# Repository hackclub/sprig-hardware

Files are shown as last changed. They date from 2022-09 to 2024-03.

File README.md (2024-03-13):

# This repository has been deprecated. This project is now maintained at https://github.com/hackclub/sprig/tree/main/hardware
## If you're looking for instructions on assembling your sprig, check out our [assembly guide!](https://github.com/hackclub/sprig/blob/main/docs/ASSEMBLY.md)

---

## The Sprig Console

You can find KiCAD 6 files for the PCB of Sprig, a BOM, and CAD models for the acrylic back covers here.

- `hardware/` contains the KiCAD files and Bill of Materials for the PCB
- `back_covers/` contains the CAD models for the acrylic back covers

The main [Sprig Repo is available here](https://www.github.com/hackclub/sprig).

Assembled Green Sprig, Front View

Assembled Green Sprig, Rear View

# Description

The Sprig console is a custom-designed, limited edition game console powered by the Raspberry Pi Pico. It has a 1.8" 160x128 LCD display, as well as eight tactile buttons for input. It uses two AAA batteries for power, and has a MAX98357A audio amplifier with an 8 ohm, 300mW Speaker.

The Sprig console is a custom-designed, limited edition game console built to run games written with the Sprig game editor.

It's powered by a Raspberry Pi RP2040, which is clocked at 125MHz, with 264kB SRAM and 2MB external QSPI flash. Four unused GPIO pins are exposed to the rear of the console.

The Sprig is powered by two AAA batteries. There is also a high efficiency schottky diode to prevent power flow to the batteries when connected to USB power.

In addition, there is a MAX98357A class D audio amplifier from Maxim Integrated, connected to a CUI Devices CVS-1508 8 ohm, 300mW speaker.

There are two LEDs for status, a power switch for batteries, as well as eight tactile buttons to control input.

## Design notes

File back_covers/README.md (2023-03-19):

# Back Covers for Sprig



`sprig_cover.f3d` is the Fusion 360 file for the back cover. The back covers can be secured with M2 x 10mm screws and hex nuts.

If you choose to fabricate the back covers using a laser cutter, you'll need 2 pieces which are `sprig_cover--dpad.dxf` and `sprig_cover--solid.dxf`. One piece has a d-pad cutout for the buttons. It's designed to be cut out of 1/8" or 3mm acrylic.

To fabricate the back covers using a 3D printer, you'll need to print 2 of the `sprig_cover--dpad.stl` and 2 of the `sprig_cover--solid.stl`.

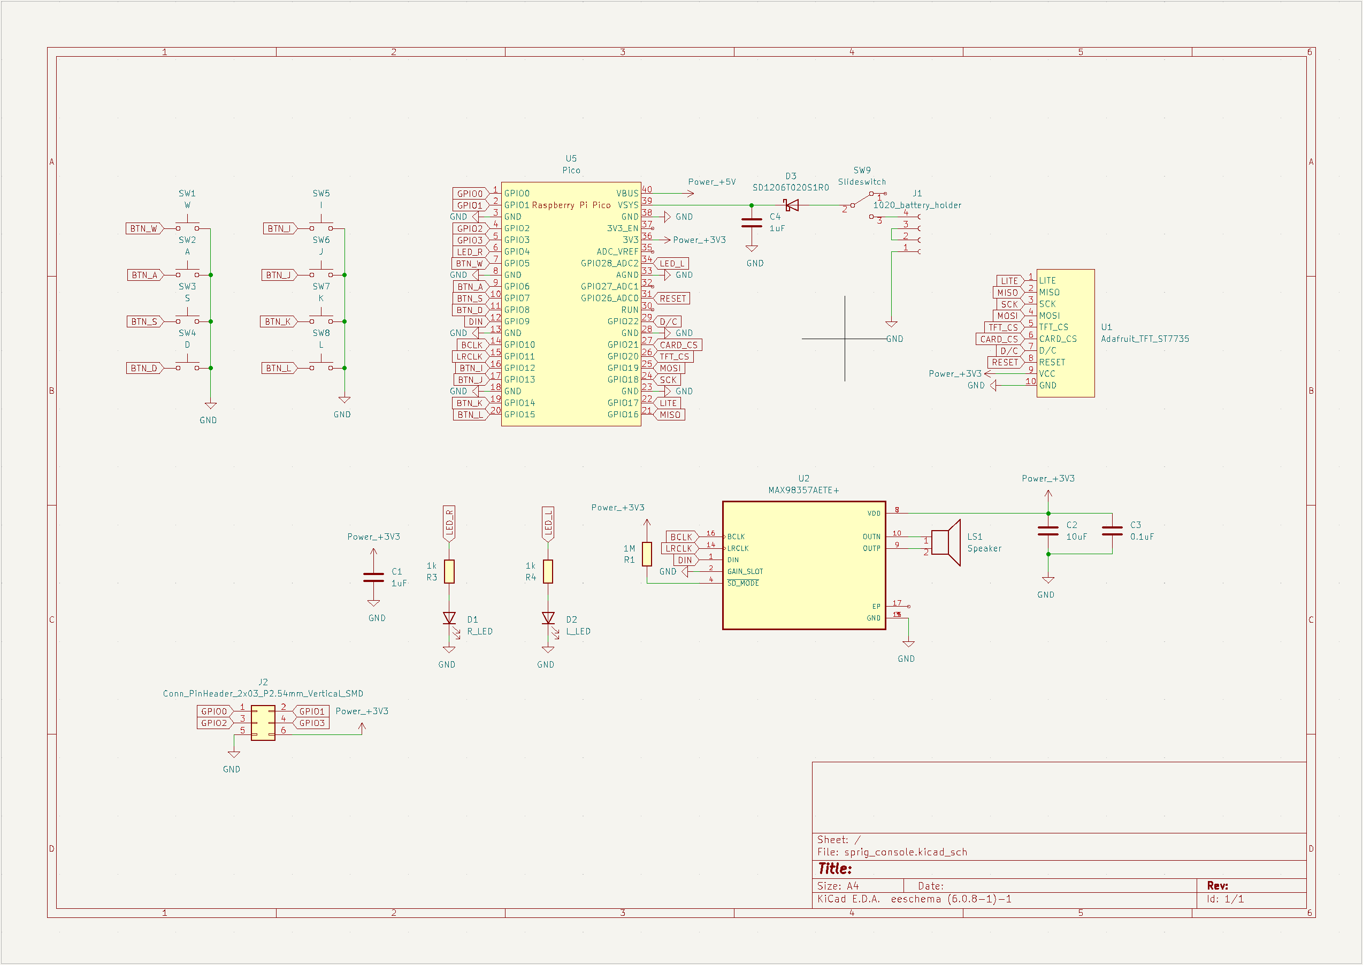
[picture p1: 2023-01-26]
hardware/schematic.png

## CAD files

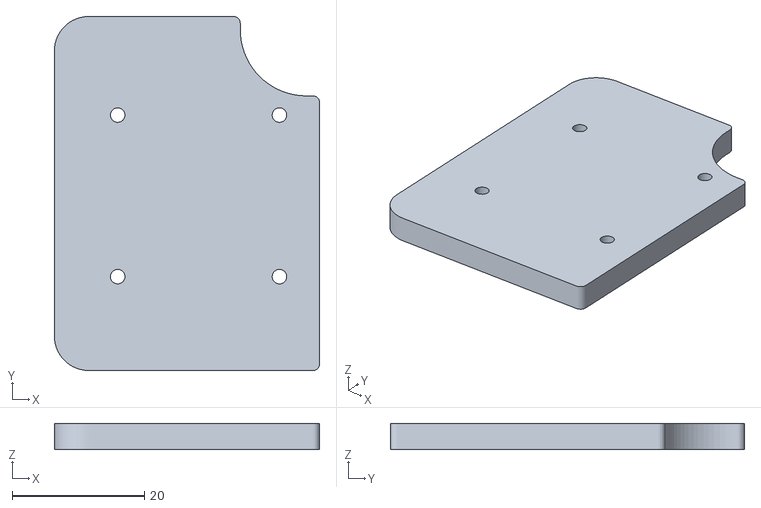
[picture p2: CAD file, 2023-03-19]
back_covers/sprig_cover--solid.stl
40.1 x 53.5 x 4.00

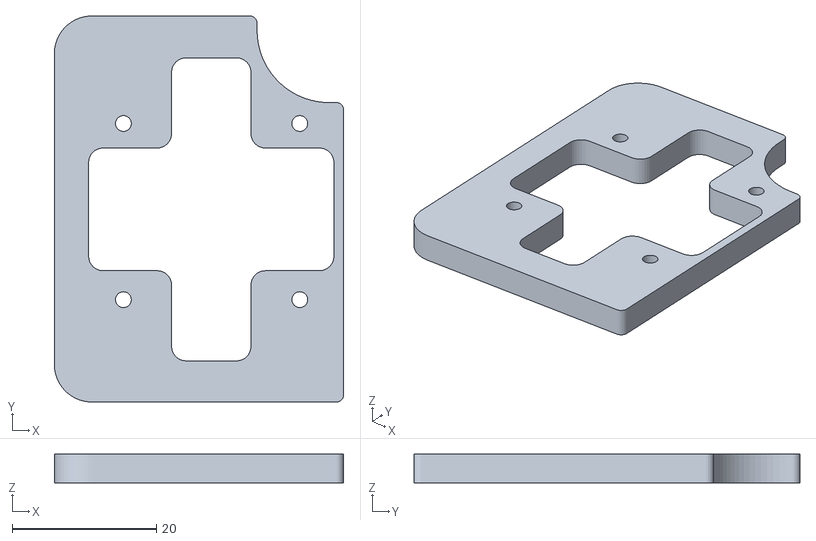
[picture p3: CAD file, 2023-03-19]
back_covers/sprig_cover--dpad.stl
40.1 x 53.5 x 4.00

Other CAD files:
back_covers/sprig_cover--dpad.dxf
back_covers/sprig_cover--solid.dxf
back_covers/sprig_cover.f3d

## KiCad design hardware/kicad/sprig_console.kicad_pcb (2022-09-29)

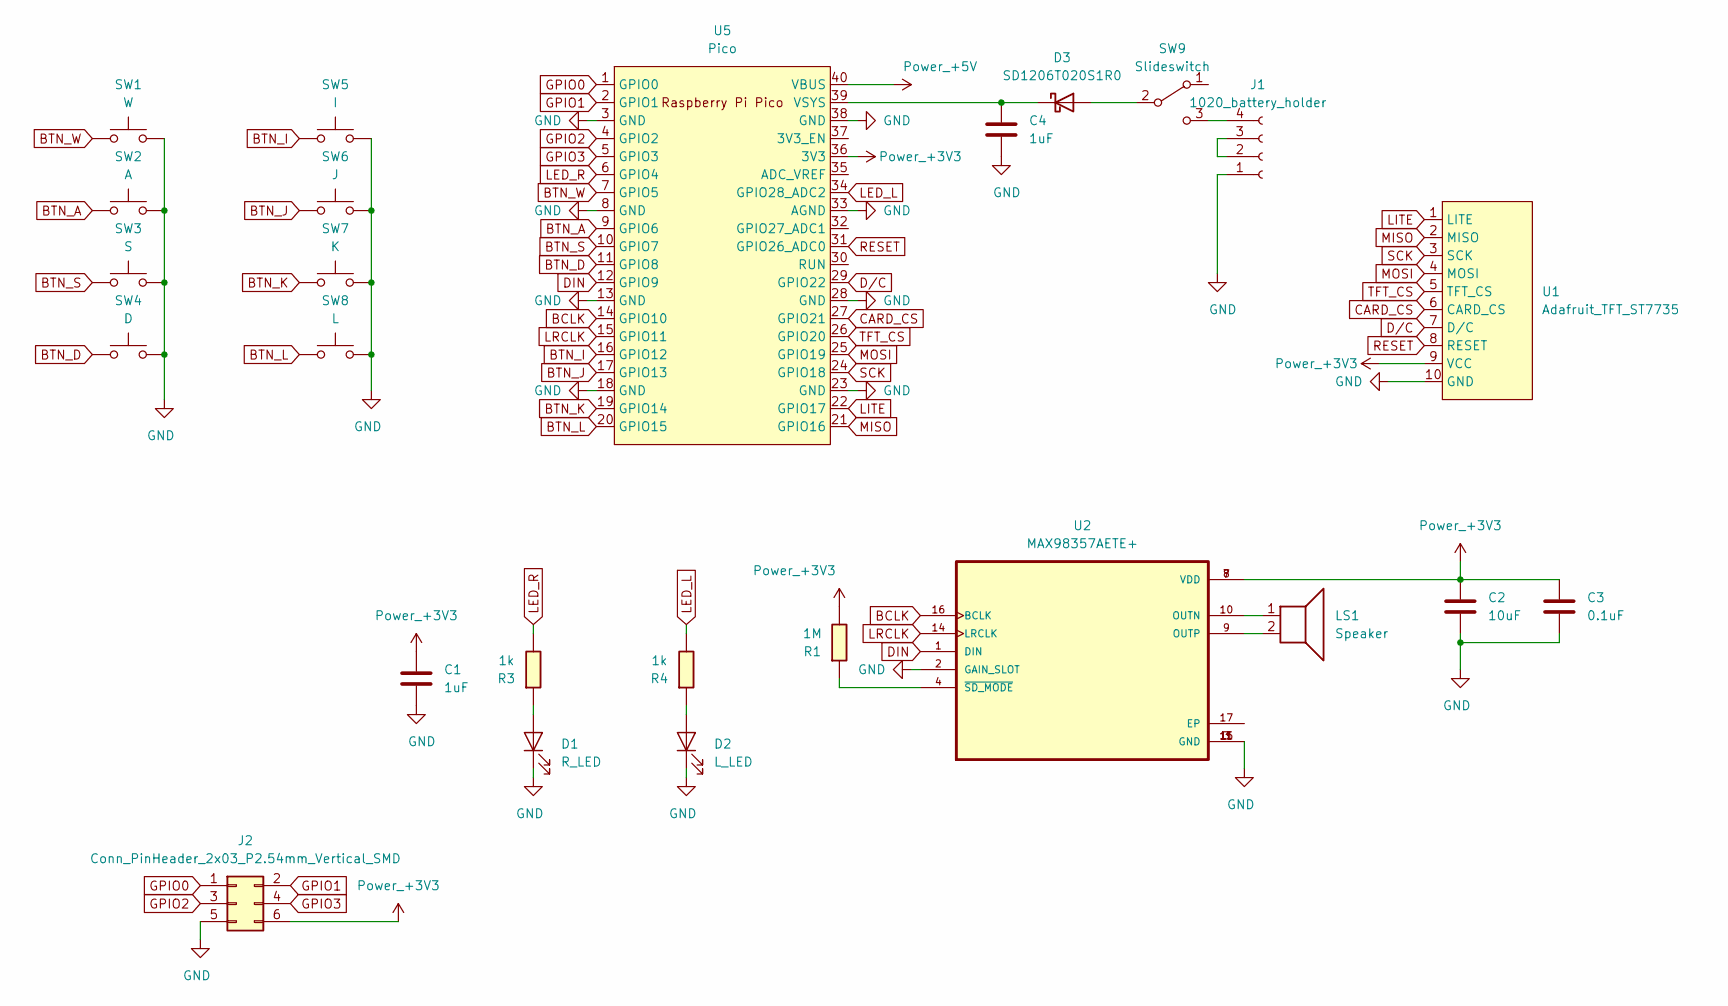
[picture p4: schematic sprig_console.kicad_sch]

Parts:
C1, C4: 1uF; C_1206
C2: 10uF; C_1206
C3: 0.1uF; C_1206
D1: R_LED; LED_1206
D2: L_LED; LED_1206
D3: SD1206T020S1R0; Diode_Schotky_100V_1A_Mini_SMA
J1: 1020_battery_holder; 1022
J2: Conn_PinHeader_2x03_P2.54mm_Vertical_SMD; PinHeader_2x03_P2.54mm_Vertical_SMD
LS1: Speaker; CVS-1508
R1: 1M; R_1206
R3, R4: 1k; R_1206
SW1: W; SW_PUSH-12mm_Wuerth-430476085716
SW2: A; SW_PUSH-12mm_Wuerth-430476085716
SW3: S; SW_PUSH-12mm_Wuerth-430476085716
SW4: D; SW_PUSH-12mm_Wuerth-430476085716
SW5: I; SW_PUSH-12mm_Wuerth-430476085716
SW6: J; SW_PUSH-12mm_Wuerth-430476085716
SW7: K; SW_PUSH-12mm_Wuerth-430476085716
SW8: L; SW_PUSH-12mm_Wuerth-430476085716
SW9: Slideswitch; slideswitchCK
U1: Adafruit_TFT_ST7735; TFT_ST7735
U2: MAX98357AETE+; QFN50P300X300X80-17N
U5: Pico; RPi_Pico_SMD_TH_mod

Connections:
+3V3: C1.1, C2.1, C3.1, J2.6, R1.1, U1.9 (VCC), U2.7 (VDD), U2.8 (VDD), U5.36 (3V3)
+5V: U5.40 (VBUS)
BCLK: U2.16 (BCLK), U5.14 (GPIO10)
BTN_A: SW2.1, U5.9 (GPIO6)
BTN_D: SW4.1, U5.11 (GPIO8)
BTN_I: SW5.1, U5.16 (GPIO12)
BTN_J: SW6.1, U5.17 (GPIO13)
BTN_K: SW7.1, U5.19 (GPIO14)
BTN_L: SW8.1, U5.20 (GPIO15)
BTN_S: SW3.1, U5.10 (GPIO7)
BTN_W: SW1.1, U5.7 (GPIO5)
CARD_CS: U1.6 (CARD_CS), U5.27 (GPIO21)
DIN: U2.1 (DIN), U5.12 (GPIO9)
D/C: U1.7 (D/C), U5.29 (GPIO22)
GND: C1.2, C2.2, C3.2, C4.2, D1.1 (K), D2.1 (K), J1.1, J2.5, SW1.2, SW2.2, SW3.2, SW4.2, SW5.2, SW6.2, SW7.2, SW8.2, U1.10 (GND), U2.2 (GAIN_SLOT), U2.3 (GND), U2.11 (GND), U2.15 (GND), U5.3 (GND), U5.8 (GND), U5.13 (GND), U5.18 (GND), U5.23 (GND), U5.28 (GND), U5.33 (AGND), U5.38 (GND)
GPIO0: J2.1, U5.1 (GPIO0)
GPIO1: J2.2, U5.2 (GPIO1)
GPIO2: J2.3, U5.4 (GPIO2)
GPIO3: J2.4, U5.5 (GPIO3)
LED_L: R4.1, U5.34 (GPIO28_ADC2)
LED_R: R3.1, U5.6 (GPIO4)
LITE: U1.1 (LITE), U5.22 (GPIO17)
LRCLK: U2.14 (LRCLK), U5.15 (GPIO11)
MISO: U1.2 (MISO), U5.21 (GPIO16)
MOSI: U1.4 (MOSI), U5.25 (GPIO19)
unnamed: C4.1, D3.1 (K), U5.39 (VSYS)
unnamed: D1.2 (A), R3.2
unnamed: D2.2 (A), R4.2
unnamed: D3.2 (A), SW9.2 (B)
unnamed: J1.2, J1.3
unnamed: J1.4, SW9.3 (C)
unnamed: LS1.1, U2.10 (OUTN)
unnamed: LS1.2, U2.9 (OUTP)
unnamed: R1.2, U2.4 (~SD_MODE)
RESET: U1.8 (RESET), U5.31 (GPIO26_ADC0)
SCK: U1.3 (SCK), U5.24 (GPIO18)
TFT_CS: U1.5 (TFT_CS), U5.26 (GPIO20)

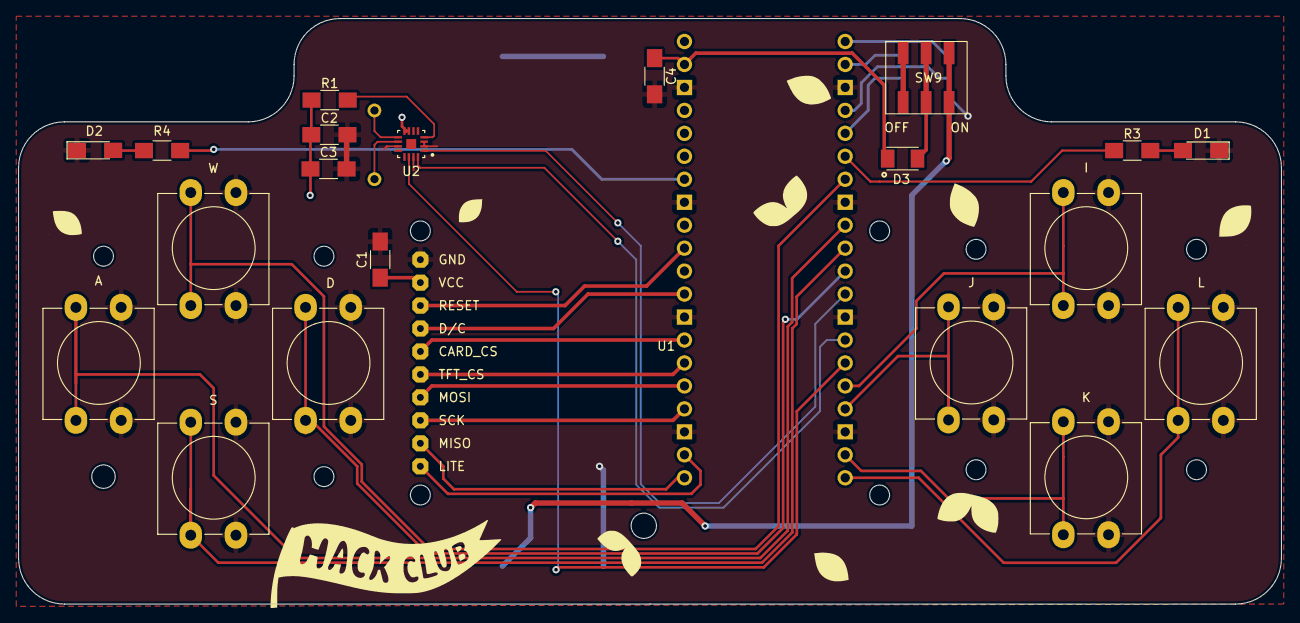
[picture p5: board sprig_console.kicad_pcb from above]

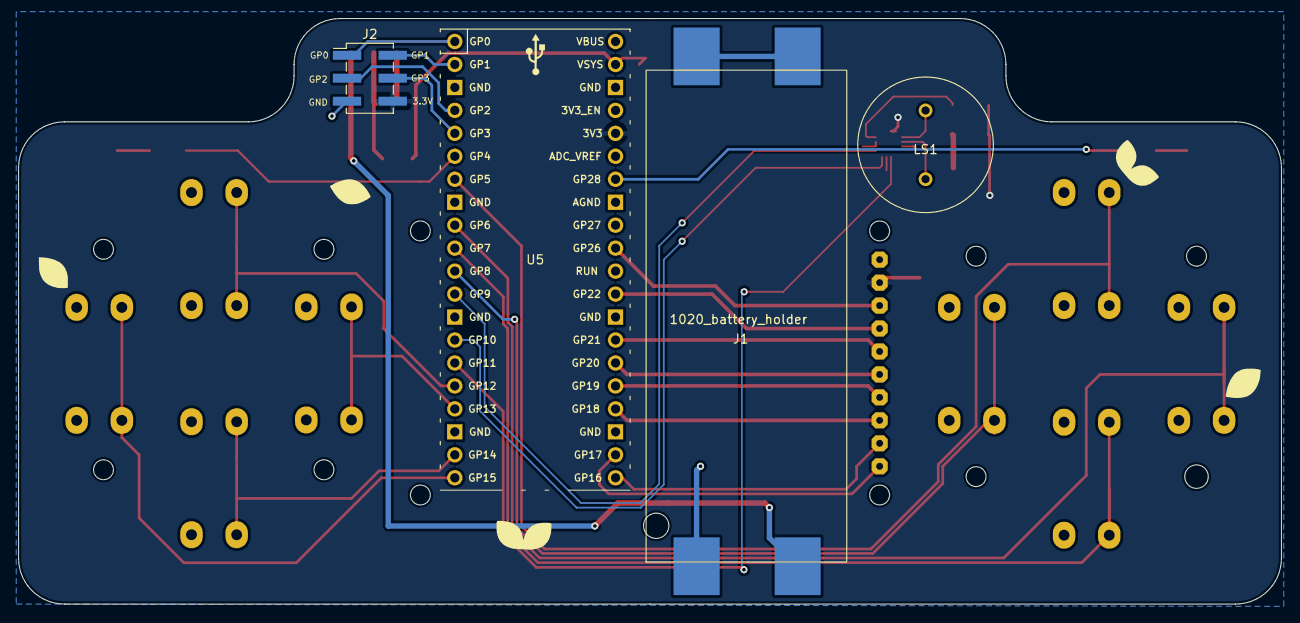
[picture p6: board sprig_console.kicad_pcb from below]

Board: 2 copper layers, 139.7 x 64.8 mm, 26 parts (5 on the bottom side), 36 nets.

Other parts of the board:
Ref**: Val**; usb

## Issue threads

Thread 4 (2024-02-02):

Feature Request: Add more accessible GPIO

polypixeldev, 2024-02-02:
The Sprig is great for a lot of things, but it's a little difficult to use it as a hardware development kit with only the 4 broken out GPIO pins on the pads on the back of the device. More GPIO pins, as well as a better method of connecting them, would help a lot with this.

To do this, you could use an I2C expander chip such as the [MCP23017](https://www.adafruit.com/product/732). It doesn’t have to be that one, but it’ll provide ample IO for any purpose.

As for connecting it, I'm not sure what the best method would be.

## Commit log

2022-09-29 update copper text
    [pigame_pico-B_Cu.gbr, pigame_pico-B_Mask.gbr, pigame_pico-B_Paste.gbr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]
2023-01-26 Add files for back covers
    [sprig_cover--dpad.dxf, sprig_cover--solid.dxf, sprig_cover.f3d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]
2023-03-19 Upload STLs separately
    [sprig_cover--d-pad.dxf.stl, sprig_cover--solid.stl]
2023-03-19 Fix file name
    [sprig_cover--dpad.stl]
2023-04-17 Format BoM list
